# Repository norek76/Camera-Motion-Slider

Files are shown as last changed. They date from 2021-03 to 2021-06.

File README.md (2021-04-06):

# Camera Motion Slider with Pan Tilt Module

Hi,
since long time I was looking for a stable slider, that can handle the load of a system camera like the A7 together with heavy lenses. Second requirement was to keep the price low.

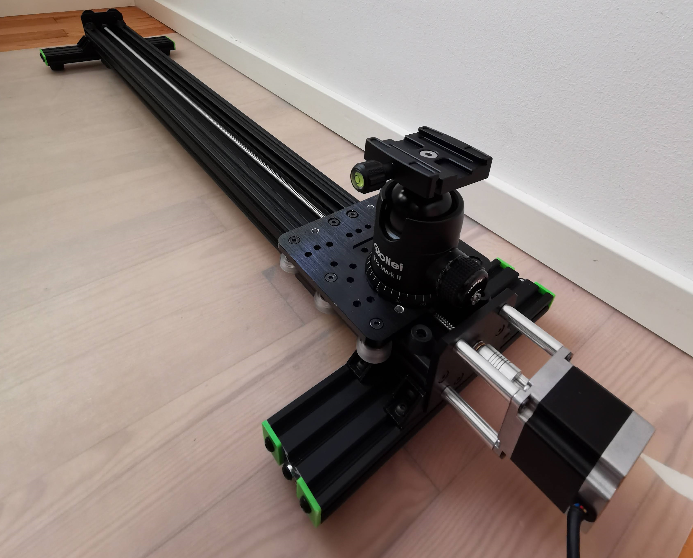
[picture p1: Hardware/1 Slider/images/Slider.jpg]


[Hardware - Slider](https://github.com/JoJ123/Camera-Motion-Slider/blob/master/Hardware/1%20Slider/README.md)

[Hardware - Pan Module](https://github.com/JoJ123/Camera-Motion-Slider/blob/master/Hardware/2%20Pan%20Module/README.md)

[Hardware - Tilt Module](https://github.com/JoJ123/Camera-Motion-Slider/blob/master/Hardware/3%20Tilt%20Module/README.md)

[Hardware - Controller](https://github.com/JoJ123/Camera-Motion-Slider/blob/master/Hardware/Controller/README.md)

[Software - ESP32](https://github.com/JoJ123/Camera-Motion-Slider/blob/master/Software/README.md)

[Software - Android](https://github.com/JoJ123/Camera-Motion-Slider/blob/master/Software/AndroidApp/README.md)

## Hardware Components
So here we are after 4 months of drawing, sketching and development here is the slider with pan and tilt module. It's a modular system with the following components:

 - Slider
 - Pan Module
 - Tilt Module

You can connect the three modules in the following configurations:
 - Slider
 - Slider with Pan Module (f.e. Timelapse)
 - Slider with Pan + Tilt Module (f.e. Timelapse)
 - Pan + Tilt Module (f.e. 360° Pano)

## Controller & Software
Last but not least there must be a controller. I started first to develope my "own" motion control library, after few weeks I stopped. And search for existing libs out there and there is a really powerfull open source library called "DFMoCo". It's the protocoll that is used by the software Dragonframe.

So I've started to check the source code of this library, that was build for Arduino Board with just USB Serial support. I've migrated the library to support ESP32 boards together with Bluetooth 4.0 that can be used also with a Serial Bluetooth Application from Android/iOS. The ESP32 can controll up to 4 stepper motors with this library. The library is command based.
In addition to the functionalities of DFMoCo I've added the possibility to focus / shutter an image of the camera with a headphone jack. Most camera manufactors support this way.

To be able to controll the slider also outside of my home I found a really good powerbank from the company XTPower. Product Name: [XT-20000QC3](https://www.xtpower.de/XT-20000Q3-Powerbank-mobiler-externer-USB-Akku-mit-20100mAh)
With this PowerBank I'm was able to reach the following operation times:
- 1 motor:  7.5h
- 2 motors: 5h
- 3 motors: 2.5h

You can easily connect two of them to increase the time. There is also a newer version of the PowerBank [XT-20000QC3-AO-PA](https://www.xtpower.de/XT-20000Q3-AO-PA-Powerbank-ohne-Abschaltung) without the automatic turnoff, when the power consumption is below 4-5W. If you build your controller wihtout a fan f.e. it would be better to choose this model, to keep the microcontroller running.
 
Possible commands:
- Move Motor 1-4 to position x
- Set Speed / Acc Ramp
- Focus / Shutter Camera Controll
- Timelapse with start / end position, timer, image shutter
- Panorama (full squere possible)

The controller for sure still supports the Dragonframe software.

To control the Slider / Camera Module easily also outside of the home, I've written a small Android application.

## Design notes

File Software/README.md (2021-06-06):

# DFMocoESP32
Forked from Dragonframe DFMoCo v.1.3.1

## Open Points
- Panorama Delay 100 after image shot

## Migration for ESP32-WROOM-32 Board (ESP32-DevKitC V4)
- channel 1
  - PIN  16   step
  - PIN  17   direction
- channel 2
  - PIN  18   step
  - PIN  19   direction
- channel 3
  - PIN  22   step
  - PIN  23   direction
- channel 4
  - PIN  32   step
  - PIN  33   direction
  
## Serial over USB / Bluetooth
If you want to use Bluetooth Classic, you have to set Pin35 to HIGH(Vcc), after that you can connect any Serial Bluetooth Application to the Board. The name of the bluetooth device is _DFMoCo_BT_.

## Camera Mode
You can check the different status codes at the code (~line 320)
```
cm --> Current camera mode status
- Timelapse: cm 1 [status] [executionStatus] [currentImageCounter] [imagesCount] 
- Panorama: cm 2 [status] [executionStatus] [currentRowCounter] [imagesRow] [currentColumnCounter] [imagesColumn] [exposureTimeMillis] [restMoveTime]

cr --> Reset camera mode
```

## Timelapse
Shoot a standalone timelapse, after the setup you can disconnect the phone. // TODO UPDATE!
```
tl [imageCount] [intervalSeconds] [exposureTimeMilliSeconds] [motionRestTimeMilliSeconds] [[motorNumber] [startPosition] [endPosition]]*
```
Example:
100 images, interval 5 seconds, exposure 150ms, restTimeAfterMovement 50ms, Motor1: 0 --> 1000, Motor2: 0 --> 500
```
tl 100 5 150 50 1 0 1000 2 0 500
```
## Panorama
Shoot a standalone timelapse, after the setup you can disconnect the phone.
```
pa [motorNumber] [imagesRow] [stepsRow] [motorNumber] [imagesColumn] [stepsColumn] [exposureTimeMilliSeconds] [motionRestTimeMilliSeconds]
```
Example:
30° Row, 30° Column --> 360°/30° = 12 Images, 200Row, 400 Column, Motor1: 0, Motor2: 0
```
pa 1 12 200 2 12 400 1000 5000
```

## Version History
- Version 1.6.0 Timelapse Multi Position with Ramping
- Version 1.5.2 Add standalone panorama mode
- Version 1.5.1 Add standalone timelapse mode
- Version 1.5.0 Add Camera Focus / Shutter
- Version 1.4.1 Support acceleration
- Version 1.4.0 ESP32-WROOM-32 support with Serial Bluetooth Classic
- Version 1.3.1 Report if go-motion speed cannot be reached.
- Version 1.3.0 Arduino 101 support. Remove non-Arduino support (chipKit, Maple).
- Version 1.2.7 Direction setup time.
- Version 1.2.6 Add PINOUT_VERSION option to use older pinout.
- Version 1.2.5 Fix jogging with low pulse rate.
- Version 1.2.4 Fix pin assignments
- Version 1.2.3 New Position command
- Version 1.2.2 Jog and Inch commands
- Version 1.2.1 Moved step/direction pins for motions 5-8. Detects board type automatically.
- Version 1.2.0 Basic go-motion capabilities
- Version 1.1.2 Smooth transitions when changing direction
- Version 1.1.1 Save/restore motor position
- Version 1.1.0 Major rework 
- Version 1.0.2 Moved pulses into interrupt handler
- Version 1.0.1 Added delay for pulse widths  
- Version 1.0.0 Initial public release.

"board": "espressif:esp32:esp32",
"configuration": "PSRAM=disabled,PartitionScheme=default,CPUFreq=240,FlashMode=qio,FlashFreq=80,FlashSize=4M,UploadSpeed=921600,DebugLevel=none",

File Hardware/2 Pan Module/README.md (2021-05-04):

# Pan Module
For the pan module I was trying multiple approaches (F.e. "Pulleys with a strip or Nema23 alone"). The problem was, that the components became to huge.
In the end I found a really simple way. It's a direct connection between the Motor (Nema17 with a planetary gearbox) and a Mengs DM-60 Base. I've designed my own motor mount plate.

I'm using here an additional Mengs FNR-140 to center the nodal point of the camera lens in the rotation axis.

I've chosen here an Nema17 with 1.8° per Full Step together with a 27:1 Gearbox

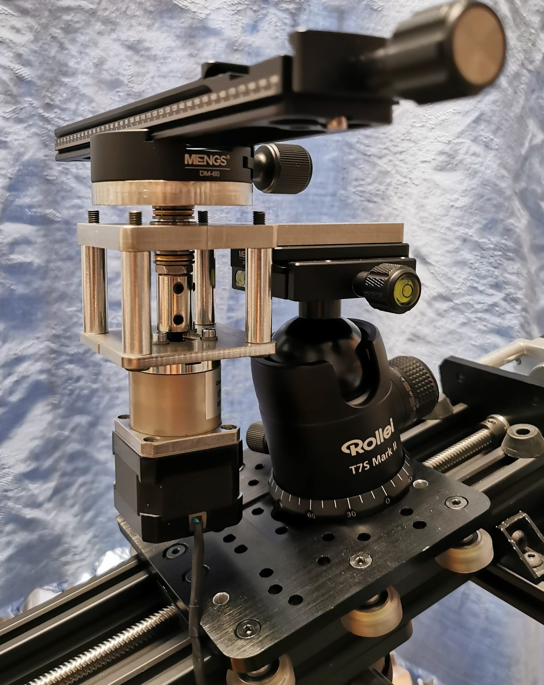
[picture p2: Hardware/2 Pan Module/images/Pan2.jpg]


```
I can't promise that this list is complete
```

Part List Pan:
* Motor Pan Plate (check the [step file](https://github.com/JoJ123/Camera-Motion-Slider/blob/master/Hardware/2%20Pan%20Module/parts/MotorPanModule.step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) & [drawing](https://github.com/JoJ123/Camera-Motion-Slider/blob/master/Hardware/2%20Pan%20Module/parts/MotorPanModule.pdf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))
* Motor Adapter Plate (check the [step file](https://github.com/JoJ123/Camera-Motion-Slider/blob/master/Hardware/2%20Pan%20Module/parts/MotorAdapterPlate.step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) & [drawing](https://github.com/JoJ123/Camera-Motion-Slider/blob/master/Hardware/2%20Pan%20Module/parts/MotorAdapterPlate.pdf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))
* Camera Base Plate (check the [step file](https://github.com/JoJ123/Camera-Motion-Slider/blob/master/Hardware/2%20Pan%20Module/parts/CameraBasePlate.step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) & [drawing](https://github.com/JoJ123/Camera-Motion-Slider/blob/master/Hardware/2%20Pan%20Module/parts/CameraBasePlate.pdf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))
* Nema17 1.8degree (max 2.0A) 27:1 Gearbox (check the max length!)
* Motor Coupling Fixed Version! 
* Spacers (40mm) (4x)
* Center Screw M8 (1x)
* Mengs DM-60 (1x)
* Mengs PU-70 (1x)
* iShoot QS-120 (1x)
* 16x8x5 Radial Flanged Bearing (688ZZ Flanged) (2x)
* 16x8x5 Axial Bearing (Silber/Gold) (2x)
+ M8 Nut (DIN 439) Thin Version (1x)
* Washers & Screws
  * 12x8 Washer
  * Screws (M5)

## Assembly
Cut the M5 thread in the Camera Base Plate & Motor Pan Plate
Connect all part like on the images below.

The stack will look like that:

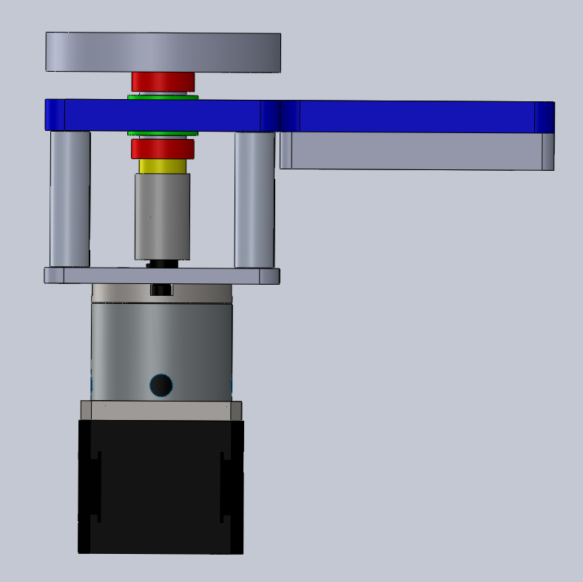
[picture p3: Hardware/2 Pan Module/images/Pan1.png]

- Red is the 16x8x5 Axial Bearing
- Green is the 688ZZ Flanged
- Gray is a 12x8 Washer
- Ignore the flexible motor coupling, it must be a fixed one here!
- I've used a flanged screw from the top to the bottom. Starting from the Mengs DN-60 that is fixed on top of the camera plate.

## Pan Module Image
You can also use the pan module directly on a tripod, as the base for an panorma image.

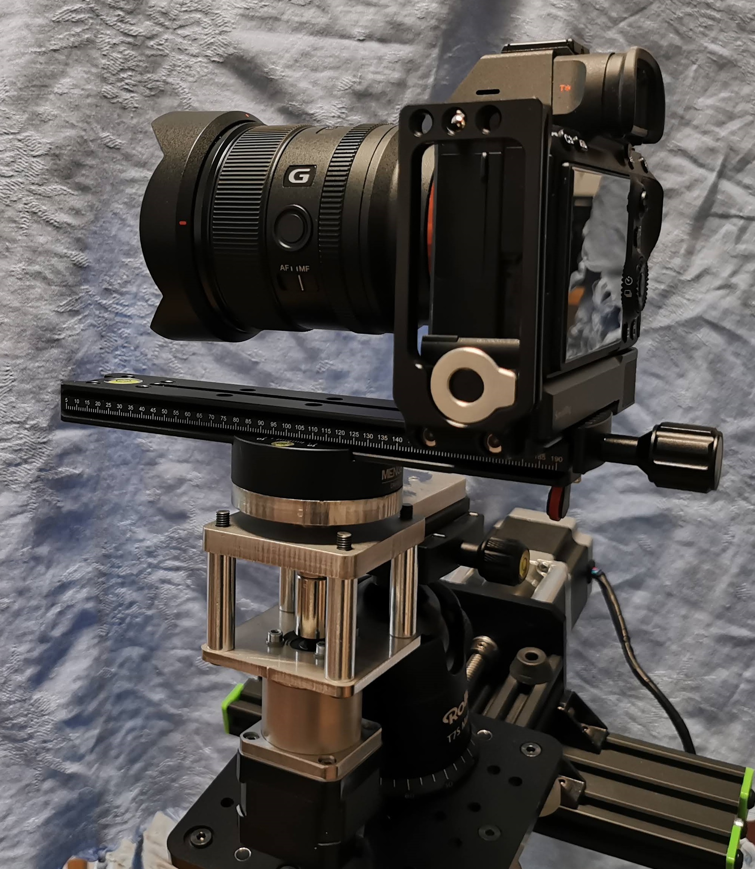
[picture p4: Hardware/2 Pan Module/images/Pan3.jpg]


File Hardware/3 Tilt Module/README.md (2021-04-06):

# Tilt Module
The tilt module is similar to the pan module, just some plates are different.

I'm also using here the same Mengs FNR-140 to center the camera in the rotation axis.

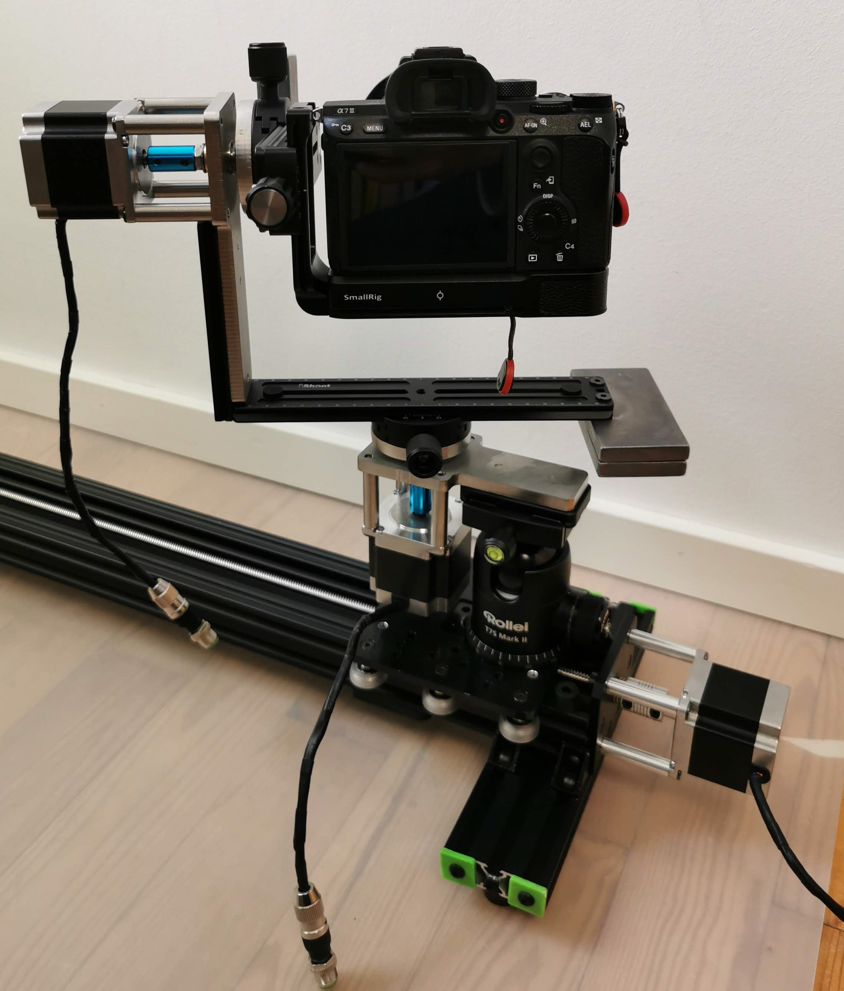
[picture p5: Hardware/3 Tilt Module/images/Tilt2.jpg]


```
I can't promise that this list is complete
```

Part List Tilt:
* Motor Tilt Plate (check the [step file](https://github.com/JoJ123/Camera-Motion-Slider/blob/master/Hardware/3%20Tilt%20Module/parts/MotorTiltModule.step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) & [drawing](https://github.com/JoJ123/Camera-Motion-Slider/blob/master/Hardware/3%20Tilt%20Moduleparts/MotorTiltModule.pdf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))
* Camera Base Plate (check the [step file](https://github.com/JoJ123/Camera-Motion-Slider/blob/master/Hardware/3%20Tilt%20Module/parts/CameraBasePlate.step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) & [drawing](https://github.com/JoJ123/Camera-Motion-Slider/blob/master/Hardware/3%20Tilt%20Module/parts/CameraBasePlate.pdf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))
* Nema23 0.9degree (max 2.0A)
* Motor Coupling Fixed Version! 
* Spacers (40mm) (4x)
* Center Screw M8 (1x)
* Mengs DM-60 (1x)
* Mengs PU-70 (1x)
* iShoot QS-120 (1x)
* iShoot QS-220 (1x)
* 16x8x5 Radial Flanged Bearing (688ZZ Flanged) (2x)
* 16x8x5 Axial Bearing (Silber/Gold) (2x)
+ M8 Nut (DIN 439) Thin Version (1x)
* Washers & Screws
  * 12x8 Washer
  * Screws (M5)

## Assembly
Cut the M5 thread in the Camera Base Plate & Motor Tilt Plate
Connect all part like on the images below.

The stack will look like that:

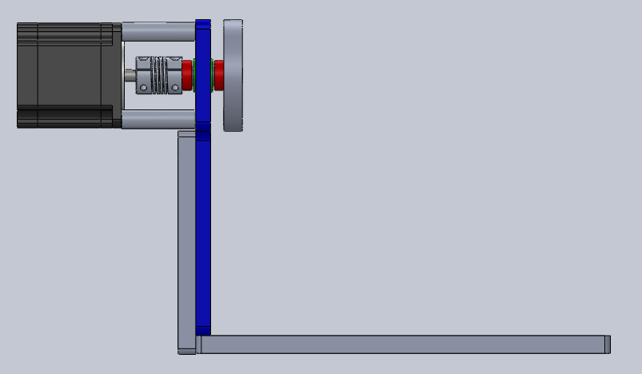
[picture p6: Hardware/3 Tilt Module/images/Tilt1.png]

- Red is the 16x8x5 Axial Bearing
- Green is the 688ZZ Flanged
- Gray is a 12x8 Washer
- Ignore the flexible motor coupling, it must be a fixed one here!
- I've used a flanged screw from the right to the left. Starting in the Mengs DN-60 that is fixed on the camera plate

## Tilt Module Images
You can use the pan & tilt module together as a 360° panorama head.
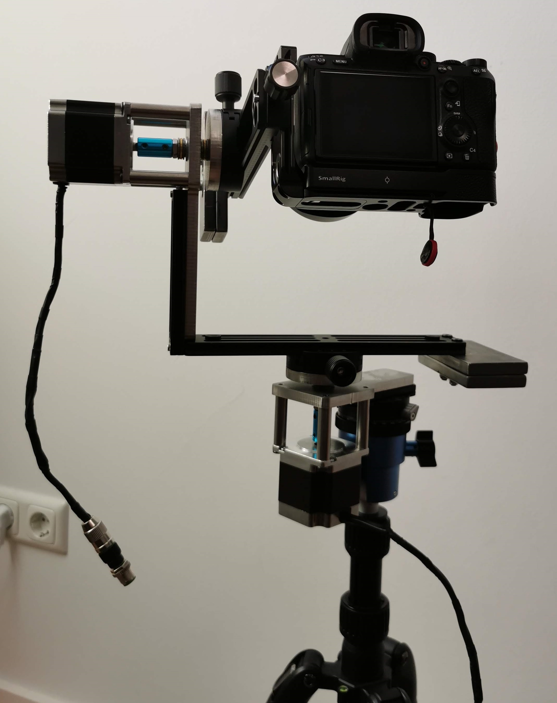
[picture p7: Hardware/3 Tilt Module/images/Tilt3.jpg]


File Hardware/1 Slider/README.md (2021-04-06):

# Base with Pan

The base for the slider was build from parts available under the "OpenBuild" Brands. I was ordering my stuff from a seller in Portugal, that is shipping to Germany. Some parts like the Motor Mount Plate is a bit different in their store. The following list is build from the parts available at this seller.
Some other parts like motors, ... were ordered by ebay.

I've chosen here an Nema23 with 1.8°/Full Step
The Lead Screw will move the slider 8mm with one rotation.



```
I can't promise that this list is complete
```

Part List Base:
* 1m C*Beam
* Motor Mount Plate (2x) --> The new one with 4 motor screws
* 16x8x5 Radial Bearing (688ZZ) (2x)
* 16x8x5 Axial Bearing (Silber/Gold) (2x)
* ACME 8mm Lead Screw (1040mm)
* Nema23 1.8degree (max 2.0A)
* Motor Coupling
* Nut Block for 8mm Metric Acme Lead Screw (2x)
* Spacers (3mm) (4x)
* Spacers (40mm) (4x)
* C-Beam Gantry Plate - XLarge
* Solid V Wheel Kit (6x)
* Spacers 6mm (3x)
* Excentric Spacers (3x)
* Rollei T7S Mark II (Or any other heavy ballhead)
* Arca Swiss Plates (2x)
* Big Tripod Plates (2x)
* Washers & Screws
  * 12x8
  * Screws

## Motor Connection
I'm using M12 Sensor Connector. I got a few of them for a good price, but you can use mostly any connector that is available. The good thing about this M12 Sensor Plugs is, that there is also a lot of different extension cables available.

## Slider
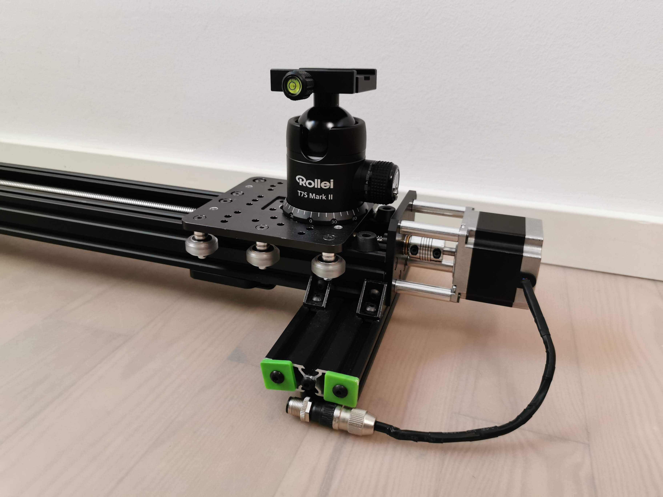
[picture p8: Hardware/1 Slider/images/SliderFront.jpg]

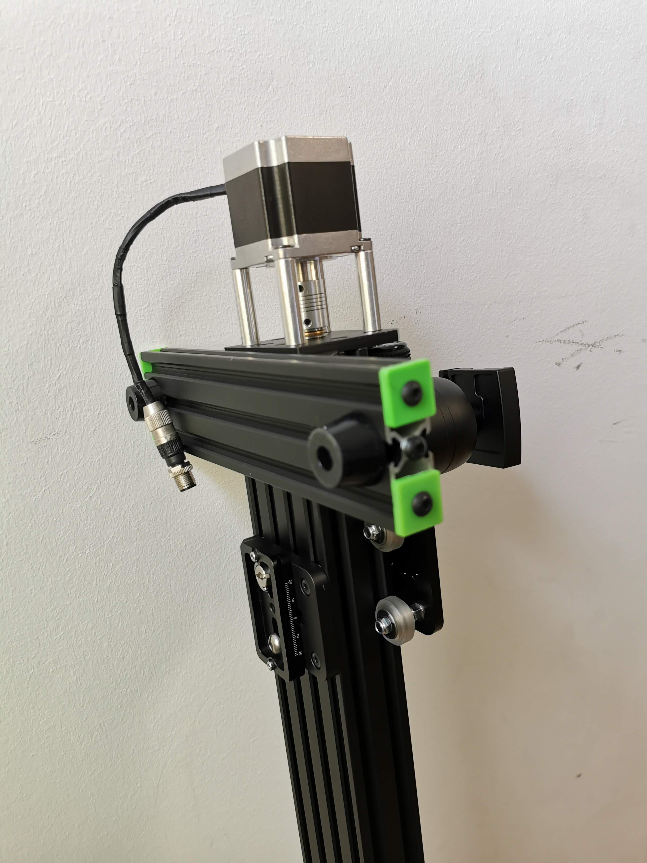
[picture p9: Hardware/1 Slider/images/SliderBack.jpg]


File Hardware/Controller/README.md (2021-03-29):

# Controller
The controller is based on a ESP32 with an CNC Shield V3 board. It looks really like a prototype :D It is a prototype.

If you have any interest in building a similar controller I would be happy to work together on a version with a PCB design. 

Contact me! :)

To be able to use the controller also outside of my home I found a really good powerbank from the company XTPower. Product Name: [XT-20000QC3](https://www.xtpower.de/XT-20000Q3-Powerbank-mobiler-externer-USB-Akku-mit-20100mAh)
With this PowerBank I'm was able to reach the following operation times:
- 1 motor:  7.5h
- 2 motors: 5h
- 3 motors: 2.5h

To connect the Powerbank to the controller you can use an XT60 to DC 5.5 2.1mm adapter, you will find it on one of the big electronic online stores or build it yourself.

You can easily connect two of them to increase the time. There is also a newer version of the PowerBank [XT-20000QC3-AO-PA](https://www.xtpower.de/XT-20000Q3-AO-PA-Powerbank-ohne-Abschaltung) without the automatic turnoff, when the power consumption is below 4-5W. If you build your controller wihtout a fan f.e. it would be better to choose this model, to keep the microcontroller running.

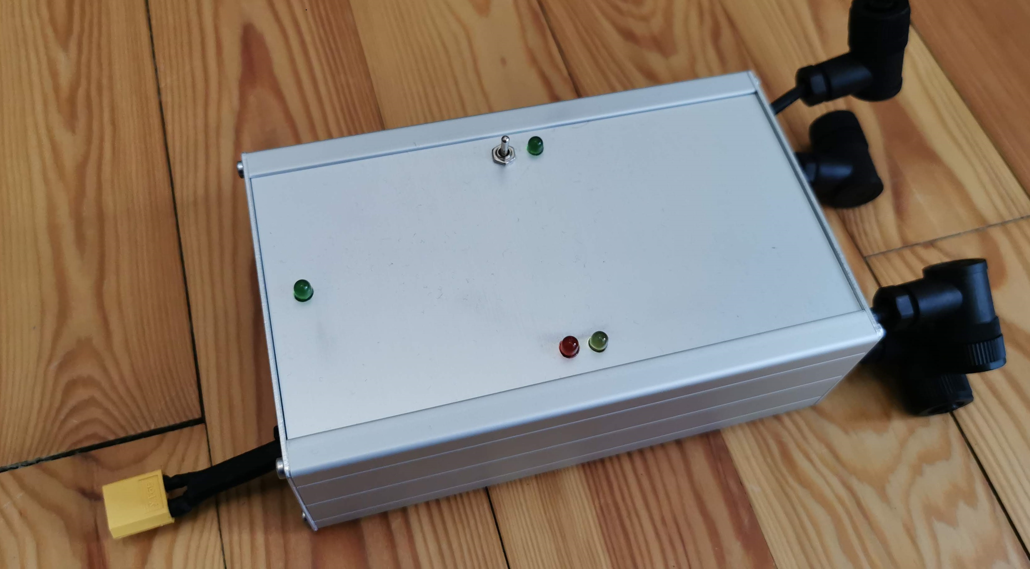
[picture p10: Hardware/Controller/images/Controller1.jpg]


Components:
- Hoisting (Proma 131030) - 168 x 103 x 56 Aluminium
- Lochrasterplatine 160mm x 100mm 
- ESP32 Dev Kit C V4
- CNC Shield v3 Board
- StepDown Board to 5V (PowerSupply ESP and fan)
- XT60 Connector
- 5V Mini Fan
- 3.5mm Audio Jack 
- PNP Transistor (for the camera focus/shutter)
- M12 Connector
- few Resistors, LEDs & Switches

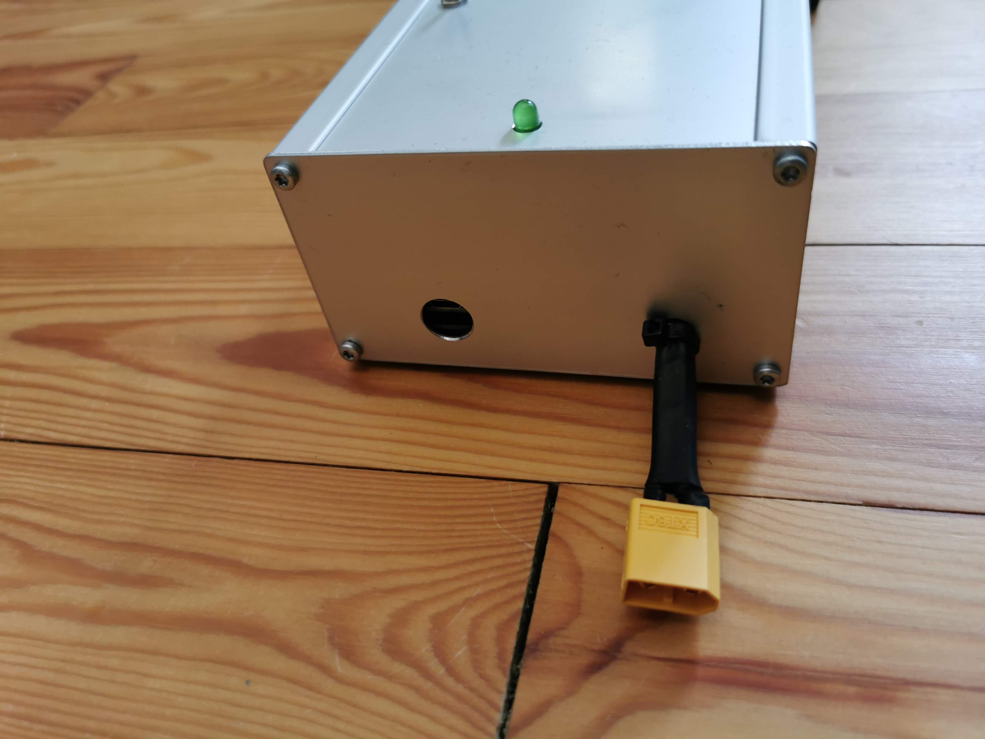
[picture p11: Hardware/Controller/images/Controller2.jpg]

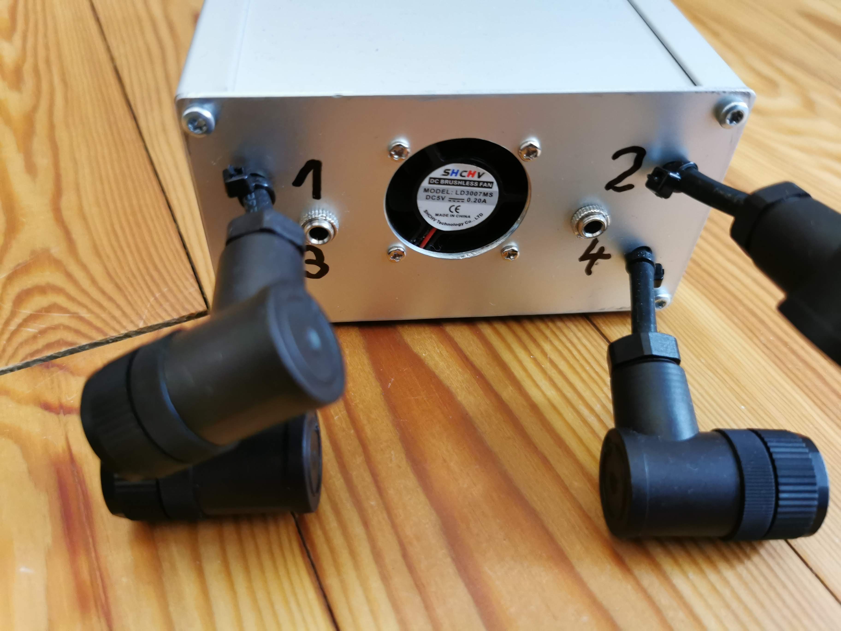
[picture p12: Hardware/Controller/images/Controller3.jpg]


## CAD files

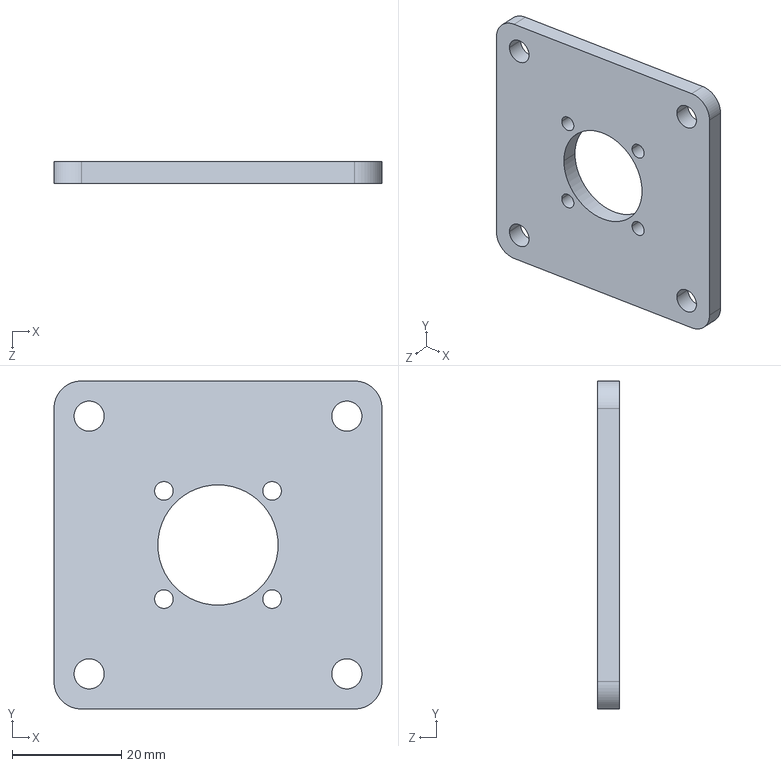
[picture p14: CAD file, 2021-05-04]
Hardware/2 Pan Module/parts/MotorAdapterPlate.step
60.0 x 60.0 x 4.00 mm

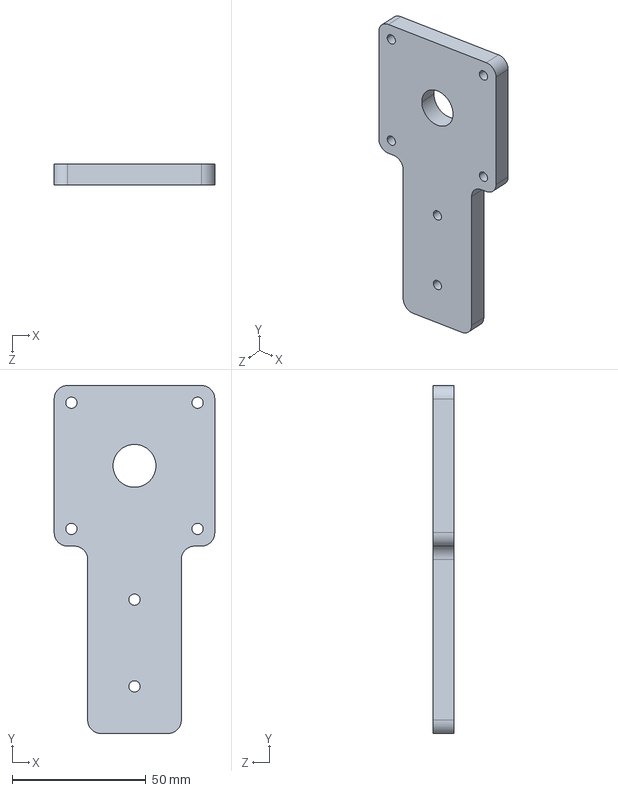
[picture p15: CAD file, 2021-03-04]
Hardware/2 Pan Module/parts/MotorPanModule.step
60.0 x 130.0 x 8.00 mm

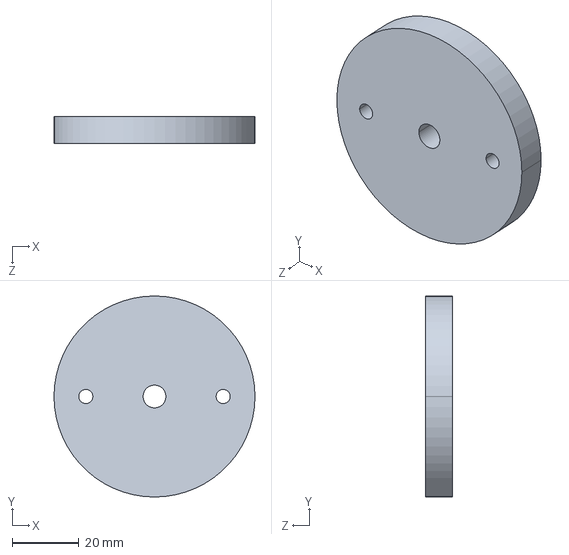
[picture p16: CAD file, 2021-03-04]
Hardware/3 Tilt Module/parts/CameraBasePlate.step
60.0 x 60.0 x 8.00 mm

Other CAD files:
Hardware/3 Tilt Module/parts/MotorTiltModule.step

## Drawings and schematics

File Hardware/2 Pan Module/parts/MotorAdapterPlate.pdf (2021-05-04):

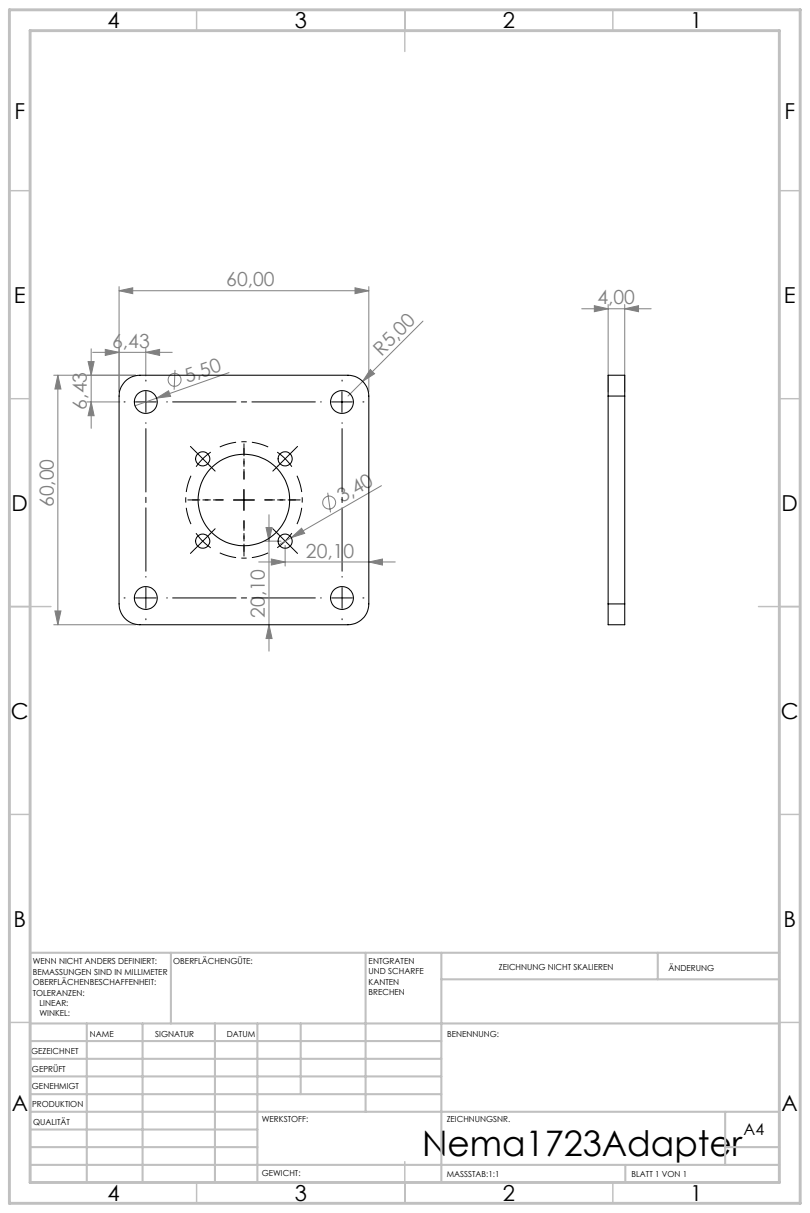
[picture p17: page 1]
MASSSTAB:1:1; BLATT 1 VON 1; ZEICHNUNG NICHT SKALIEREN; ÄNDERUNG; UND SCHARFE; WENN NICHT ANDERS DEFINIERT:; OBERFLÄCHENGÜTE:

BEMASSUNGEN SIND IN MILLIMETER
OBERFLÄCHENBESCHAFFENHEIT:
TOLERANZEN:
LINEAR:
WINKEL:

NAME | SIGNATUR | DATUM | | | | BENENNUNG:
QUALITÄT | | | | WERKSTOFF: Nema1723Adapter GEWICHT: | ZEICHNUNGSNR. | A4

GEZEICHNET
GEPRÜFT
GENEHMIGT
PRODUKTION

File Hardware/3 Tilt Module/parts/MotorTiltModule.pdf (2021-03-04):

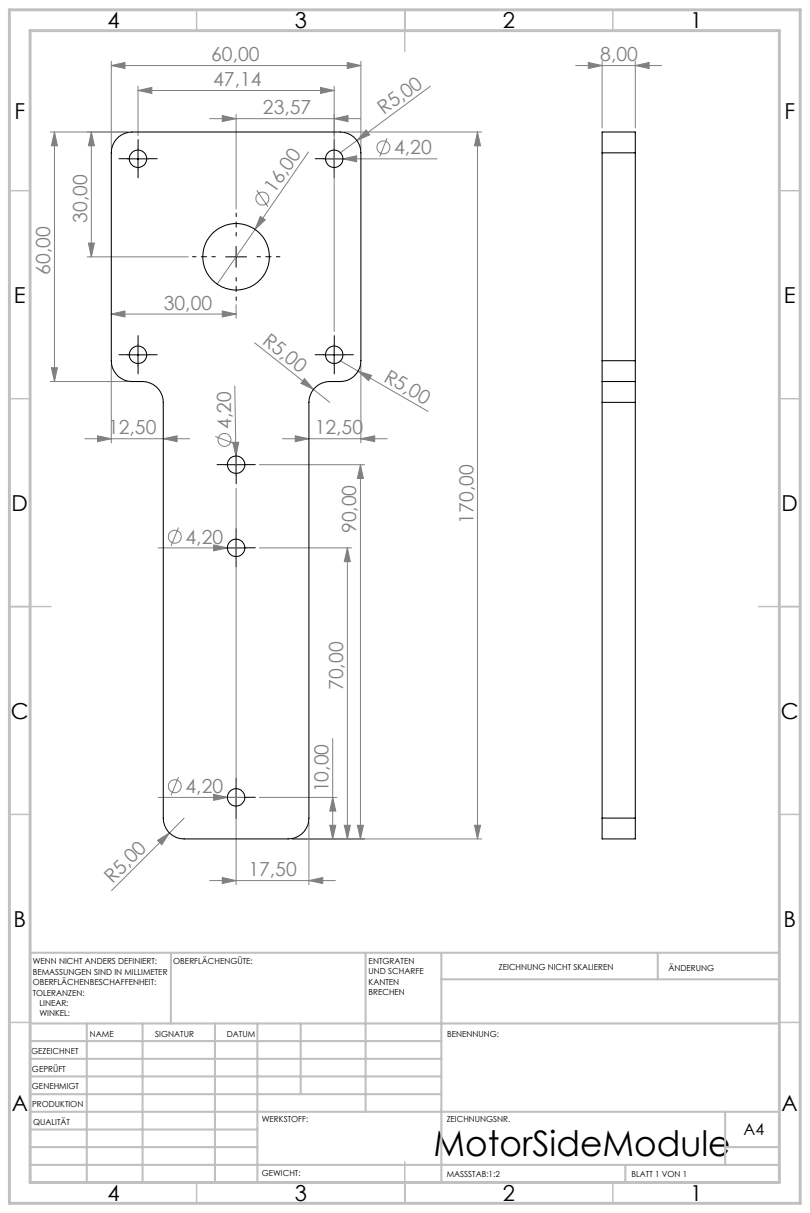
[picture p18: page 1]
MASSSTAB:1:2; BLATT 1 VON 1; ZEICHNUNG NICHT SKALIEREN; ÄNDERUNG; UND SCHARFE; WENN NICHT ANDERS DEFINIERT:; OBERFLÄCHENGÜTE:

BEMASSUNGEN SIND IN MILLIMETER
OBERFLÄCHENBESCHAFFENHEIT:
TOLERANZEN:
LINEAR:
WINKEL:

NAME | SIGNATUR | DATUM | | | | BENENNUNG:
QUALITÄT | | | | WERKSTOFF: MotorSideModule GEWICHT: | ZEICHNUNGSNR. | A4

GEZEICHNET
GEPRÜFT
GENEHMIGT
PRODUKTION

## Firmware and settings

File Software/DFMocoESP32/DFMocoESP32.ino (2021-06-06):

#include <Arduino.h>
#include <math.h>
#include <BluetoothSerial.h>

#define DFMOCO_VERSION 1
#define DFMOCO_VERSION_STRING "1.6.0"

#define USER_CMD_ARGS 40
struct UserCmd
{
  byte command;
  byte argCount;
  int32_t args[USER_CMD_ARGS];
};

boolean availableSerial();
int readSerial();
void bluetoothCallback(esp_spp_cb_event_t event, esp_spp_cb_param_t *param);
void IRAM_ATTR updateStepDirection(void);
void hardStop();
void updateMotorVelocities();
void setMaxAccelerationPerSecond(int motorIndex, uint16_t accelerationPerSecond);
void setPulsesPerSecond(int motorIndex, uint16_t pulsesPerSecond, boolean setRamp = false);
void setupMotorMove(int motorIndex, int32_t destination);
void stopMotor(int motorIndex, boolean fastStop = false, boolean hardStop = false);
boolean isValidMotor(int motorIndex);
void processGoPosition(int motorIndex, int32_t pos);
byte processUserMessage(char data);
void processSerialCommand();
void sendMessage(byte msg, byte motorIndex);
void sendMessageQueue(byte msg, byte motorIndex);
boolean jogMotor(int motorIndex, int32_t target, int32_t *destination);
void inchMotor(int motorIndex, int32_t target);
void calculatePointToPoint(int motorIndex, int32_t destination);
int32_t setupBlur(int motorIndex, int exposure, int blur, int32_t p0, int32_t p1, int32_t p2);
void IRAM_ATTR delayMilliseconds(uint32_t us);
void takeCameraImage(int delayFocus, int delayShutter);
void setCameraFocus(boolean value);
void setCameraShutter(boolean value);
void resetCameraMode();
void resetCameraModeSettings();
void processCameraMode();
void IRAM_ATTR executeTimelaseMotion(void);
void IRAM_ATTR executeTimelapseImage();
void setupTimelapse(UserCmd userCmd);
void processTimelapse();
void setupPanorama(UserCmd userCmd);
void processPanorama();

/*
  DFMoco version 1.5.2
  
  Multi-axis motion control.
  For use with the Arc motion control system in Dragonframe 4.
  Generates step and direction signals, which can be sent to stepper motor drivers.

  Version History
  Version 1.5.2 Add standalone panorama mode
  Version 1.5.1 Add standalone timelapse mode
  Version 1.5.0 Add standalone timelapse mode
  Version 1.4.1 Support acceleration
  Version 1.4.0 ESP32-WROOM-32 support with Serial Bluetooth Classic
  Version 1.3.1 Report if go-motion speed cannot be reached.
  Version 1.3.0 Arduino 101 support. Remove non-Arduino support (chipKit, Maple).
  Version 1.2.7 Direction setup time.
  Version 1.2.6 Add PINOUT_VERSION option to use older pinout.
  Version 1.2.5 Fix jogging with low pulse rate.
  Version 1.2.4 Fix pin assignments
  Version 1.2.3 New Position command
  Version 1.2.2 Jog and Inch commands
  Version 1.2.1 Moved step/direction pins for motions 5-8.
                Detects board type automatically.
  Version 1.2.0 Basic go-motion capabilities
  Version 1.1.2 Smooth transitions when changing direction
  Version 1.1.1 Save/restore motor position
  Version 1.1.0 Major rework 
  Version 1.0.2 Moved pulses into interrupt handler
  Version 1.0.1 Added delay for pulse widths  
  Version 1.0.0 Initial public release.
*/

#define SERIAL_DEVICE Serial
#define SERIAL_DEVICE_BT SerialBT
#define BLUETOOTH_LED_PIN 26

#define FOCUS_PIN 14
#define SHUTTER_PIN 27
#define ENABLE_PIN 25

#define PIN_ON(port, pin) \
  {                       \
    digitalWrite(pin, 1); \
  }
#define PIN_OFF(port, pin) \
  {                        \
    digitalWrite(pin, 0);  \
  }

#define MOTOR_COUNT 4
#define TIME_CHUNK 50
#define SEND_POSITION_COUNT 20000

// update velocities 20 x second
#define VELOCITY_UPDATE_RATE (50000 / TIME_CHUNK)
#define VELOCITY_INC(maxrate) (max(1.0f, maxrate / 70.0f))
#define VELOCITY_CONVERSION_FACTOR 0.30517578125f /* 20 / 65.536f */

#define MAX_VELOCITY 12000
#define DEFAUL_VELOCITY 1500
#define MIN_VELOCITY 100
#define MAX_ACCELERATION 2 * MAX_VELOCITY
#define MIN_ACCELERATION 2 * MIN_VELOCITY

#define MOTOR0_STEP_PORT 0
#define MOTOR0_STEP_PIN 16

#define MOTOR1_STEP_PORT 0
#define MOTOR1_STEP_PIN 18

#define MOTOR2_STEP_PORT 0
#define MOTOR2_STEP_PIN 22

#define MOTOR3_STEP_PORT 0
#define MOTOR3_STEP_PIN 32

#define TX_UCSRA UCSR0A
#define TX_UDRE UDRE0
#define TX_UDR UDR0
char txBuf[32];
char *txBufPtr;

#define TX_MSG_BUF_SIZE 16

#define MSG_STATE_START 0
#define MSG_STATE_CMD 1
#define MSG_STATE_DATA 2
#define MSG_STATE_ERR 3

#define MSG_STATE_DONE 100

/*
 * Command codes from user
 */
#define CMD_NONE 0
#define CMD_HI 10
#define CMD_MS 30
#define CMD_NP 31
#define CMD_MM 40 // move motor
#define CMD_PR 41 // pulse rate
#define CMD_SM 42 // stop motor
#define CMD_MP 43 // motor position
#define CMD_ZM 44 // zero motor
#define CMD_SA 50 // stop all (hard)
#define CMD_BF 60 // blur frame
#define CMD_GO 61 // go!

#define CMD_JM 70 // jog motor
#define CMD_IM 71 // inch motor

#define CMD_VE 80 // velocity
#define CMD_AC 81 // acceleration

#define CMD_CF 90 // camera focus
#define CMD_CS 91 // camera shutter
#define CMD_CI 92 // camera take image

#define CMD_CM 100 // camera mode
#define CMD_CR 101 // reset camera mode
#define CMD_TL 102 // timelapse
#define CMD_PA 103 // panorama

// pa 1 10 160 2 3 200 5000 1000

#define MSG_HI 01
#define MSG_MM 02
#define MSG_MP 03
#define MSG_MS 04
#define MSG_PR 05
#define MSG_SM 06
#define MSG_SA 07
#define MSG_BF 10
#define MSG_GO 11
#define MSG_JM 12
#define MSG_IM 13
#define MSG_AC 14
#define MSG_VE 15
#define MSG_CM 16
#define MSG_CR 17

#define CAM_MODE_NONE 0
#define CAM_MODE_TIMELAPSE 1
#define CAM_MODE_PANORAMA 2
#define CAM_MODE_RESETTING 10

// Timelapse Status
#define TIMELAPSE_SETUP 0
#define TIMELAPSE_RUNNING 1
#define TIMELAPSE_DONE 2
// Timelapse EXECUTION
#define TIMELAPSE_INIT_MOVEMENT 0
#define TIMELAPSE_START_EXECUTION 1
#define TIMELAPSE_REST 2
#define TIMELAPSE_IMAGE 3
#define TIMELAPSE_MOVE 4
// Timelapse Errors
#define TIMELAPSE_ERROR_INTERVAL_LT_1 10
#define TIMELAPSE_ERROR_EXPOSURE_LT_1 11
#define TIMELAPSE_ERROR_REST_LT_0 12
#define TIMELAPSE_ERROR_POSITION_COUNT_BETWEEN_2_4 13
#define TIMELAPSE_ERROR_IMAGES_LE_1 14
#define TIMELAPSE_ERROR_IMAGES_NOT_IN_ROW 15
#define TIMELAPSE_ERROR_RAMP_BETWEEN_0_40 16
#define TIMELAPSE_ERROR_ACC_RAMP 17
#define TIMELAPSE_ERROR_MOVE_SHOOT_TIME 18
#define TIMELAPSE_ERROR_POSITION 19
// Panorama Status
#define PANORAMA_SETUP 0
#define PANORAMA_RUNNING 1
#define PANORAMA_DONE 2
// Panorama Execution Status
#define PANORAMA_REST 0
#define PANORAMA_REST_RUNNING 1
#define PANORAMA_IMAGE 2
#define PANORAMA_READY_FOR_MOVE 3
#define PANORAMA_MOVE 4
#define PANORAMA_MOVE_END 5
// Panorama Errors
#define PANORAMA_ERROR_MTR_OUT 10
#define PANORAMA_ERROR_IMG_LE_1 11
#define PANORAMA_ERROR_STP_EQ_0 12
#define PANORAMA_ERROR_EXP_LT_50 13
#define PANORAMA_ERROR_RST_LT_1 14

#define MAX_POSITION_COUNT 4
#define MAX_ITERATION_COUNT MAX_POSITION_COUNT - 1

struct TimelapseMotor
{
  boolean enable;
  int32_t time[MAX_ITERATION_COUNT][4];
  double acc[MAX_ITERATION_COUNT];
  double dec[MAX_ITERATION_COUNT];
  double v0[MAX_ITERATION_COUNT];
  double v1[MAX_ITERATION_COUNT];
  uint32_t velocity;
  uint32_t acceleration;
  int32_t positions[MAX_POSITION_COUNT];
  int32_t lastPosition;
};

struct Timelapse
{
  TimelapseMotor motors[MOTOR_COUNT];
  uint32_t intervalSeconds;
  uint32_t imagesCount[3];
  uint32_t exposureTimeMillis;
  uint32_t restMoveTime;
  uint32_t ramp;
  uint32_t positionCount;
  uint32_t currentIteration;
  uint32_t currentIterationImageCounter;
  uint32_t totalImageCounter;
  uint32_t totalImages;
  byte status;
  byte executionStatus;
};

Timelapse timelapseData;

struct Panorma
{
  uint32_t motorRow;
  uint32_t imagesRow;
  int32_t stepsRow;
  uint32_t motorColumn;
  uint32_t imagesColumn;
  int32_t stepsColumn;
  uint32_t exposureTimeMillis;
  uint32_t restMoveTime;
  uint32_t restStartMillis;
  uint32_t currentRowCounter;
  uint32_t currentColumnCounter;
  byte status;
  byte executionStatus;
};

Panorma panoramaData;
/*
 * Message state machine variables.
 */
byte lastUserData;
int msgState;
int msgNumberSign;
UserCmd userCmd;

struct txMsg
{
  byte msg;
  byte motor;
};

struct TxMsgBuffer
{
  txMsg buffer[TX_MSG_BUF_SIZE];
  byte head;
  byte tail;
};

TxMsgBuffer txMsgBuffer;
BluetoothSerial SerialBT;

/*
 Motor data.
 */
uint16_t motorAccumulator0;
uint16_t motorAccumulator1;
uint16_t motorAccumulator2;
uint16_t motorAccumulator3;
uint16_t *motorAccumulator[MOTOR_COUNT] =
    {
        &motorAccumulator0,
        &motorAccumulator1,
        &motorAccumulator2,
        &motorAccumulator3,
};

uint16_t motorMoveSteps0;
uint16_t motorMoveSteps1;
uint16_t motorMoveSteps2;
uint16_t motorMoveSteps3;
uint16_t *motorMoveSteps[MOTOR_COUNT] =
    {
        &motorMoveSteps0,
        &motorMoveSteps1,
        &motorMoveSteps2,
        &motorMoveSteps3,
};

uint16_t motorMoveSpeed0;
uint16_t motorMoveSpeed1;
uint16_t motorMoveSpeed2;
uint16_t motorMoveSpeed3;
uint16_t *motorMoveSpeed[MOTOR_COUNT] =
    {
        &motorMoveSpeed0,
        &motorMoveSpeed1,
        &motorMoveSpeed2,
        &motorMoveSpeed3,
};

volatile boolean nextMoveLoaded;

unsigned int velocityUpdateCounter;
byte sendPositionCounter;

byte sendPosition = 0;
byte motorMoving = 0;
byte toggleStep = 0;

#define P2P_MOVE_COUNT 7
struct Motor
{
  byte stepPin;
  byte dirPin;

  // pre-computed move
  float moveTime[P2P_MOVE_COUNT];
  int32_t movePosition[P2P_MOVE_COUNT];
  float moveVelocity[P2P_MOVE_COUNT];
  float moveAcceleration[P2P_MOVE_COUNT];

  float gomoMoveTime[P2P_MOVE_COUNT];
  int32_t gomoMovePosition[P2P_MOVE_COUNT];
  float gomoMoveVelocity[P2P_MOVE_COUNT];
  float gomoMoveAcceleration[P2P_MOVE_COUNT];

  int currentMove;
  float currentMoveTime;

  volatile boolean positionReached;
  volatile boolean dir;

  int32_t position;
  int32_t destination;
  float maxVelocity;
  float maxAcceleration;

  uint16_t nextMotorMoveSteps;
  float nextMotorMoveSpeed;
};

boolean goMoReady;
int goMoDelayTime;

Motor motors[MOTOR_COUNT];

unsigned long lastBluetoothLedMillis = millis();
boolean serialBluetoothEnabled = false;

boolean lastBluetoothLedState = true;
hw_timer_t *timerMotion = NULL;
portMUX_TYPE timerMotionMux = portMUX_INITIALIZER_UNLOCKED;

hw_timer_t *timerCameraMode = NULL;
hw_timer_t *timerCameraModeMotion = NULL;

byte cameraMode = CAM_MODE_NONE;
QueueHandle_t messageQueue;
int messageCounter = 0;

class DualPrint : public Print
{
public:
  DualPrint() : serialBluetoothEnabled(false) {}
  virtual size_t write(uint8_t c)
  {
    if (serialBluetoothEnabled)
      SERIAL_DEVICE_BT.write(c);
    else
      SERIAL_DEVICE.write(c);
    return 1;
  }

  boolean serialBluetoothEnabled;
} dualSerial;

boolean availableSerial()
{
  if (serialBluetoothEnabled)
  {
    return SERIAL_DEVICE_BT.available();
  }
  return SERIAL_DEVICE.available();
}

int readSerial()
{
  if (serialBluetoothEnabled)
  {
    return SERIAL_DEVICE_BT.read();
  }
  return SERIAL_DEVICE.read();
}

void bluetoothCallback(esp_spp_cb_event_t event, esp_spp_cb_param_t *param)
{
  if (event == ESP_SPP_SRV_OPEN_EVT)
  {
    PIN_ON(0, BLUETOOTH_LED_PIN);
    dualSerial.serialBluetoothEnabled = true;
    serialBluetoothEnabled = true;
  }
  if (event == ESP_SPP_CLOSE_EVT)
  {
    dualSerial.serialBluetoothEnabled = false;
    serialBluetoothEnabled = false;
    lastBluetoothLedState = false;
    lastBluetoothLedMillis = millis();
    PIN_OFF(0, BLUETOOTH_LED_PIN);
  }
}

void IRAM_ATTR updateStepDirection(void)
{
  portENTER_CRITICAL_ISR(&timerMotionMux);
  toggleStep = !toggleStep;

  if (toggleStep)
  {
    // MOTOR 1
    if (motorMoveSteps0)
    {
      uint16_t a = motorAccumulator0;
      motorAccumulator0 += motorMoveSpeed0;
      if (motorAccumulator0 < a)
      {
        motorMoveSteps0--;

        PIN_ON(MOTOR0_STEP_PORT, MOTOR0_STEP_PIN);
      }
    }

    // MOTOR 2
    if (motorMoveSteps1)
    {
      uint16_t a = motorAccumulator1;
      motorAccumulator1 += motorMoveSpeed1;
      if (motorAccumulator1 < a)
      {
        motorMoveSteps1--;

        PIN_ON(MOTOR1_STEP_PORT, MOTOR1_STEP_PIN);
      }
    }

    // MOTOR 3
    if (motorMoveSteps2)
    {
      uint16_t a = motorAccumulator2;
      motorAccumulator2 += motorMoveSpeed2;
      if (motorAccumulator2 < a)
      {
        motorMoveSteps2--;

        PIN_ON(MOTOR2_STEP_PORT, MOTOR2_STEP_PIN);
      }
    }

    // MOTOR 4
    if (motorMoveSteps3)
    {
      uint16_t a = motorAccumulator3;
      motorAccumulator3 += motorMoveSpeed3;
      if (motorAccumulator3 < a)
      {
        motorMoveSteps3--;

        PIN_ON(MOTOR3_STEP_PORT, MOTOR3_STEP_PIN);
      }
    }
  }
  else
  {
    velocityUpdateCounter++;
    if (velocityUpdateCounter == VELOCITY_UPDATE_RATE)
    {
      velocityUpdateCounter = 0;

      if (sendPositionCounter)
      {
        sendPositionCounter--;
      }

      for (int i = 0; i < MOTOR_COUNT; i++)
      {
        if (*motorMoveSpeed[i] && !motors[i].nextMotorMoveSpeed)
        {
          bitSet(sendPosition, i);
        }

        *motorMoveSteps[i] = motors[i].nextMotorMoveSteps;
        *motorMoveSpeed[i] = motors[i].nextMotorMoveSpeed;
        digitalWrite(motors[i].dirPin, motors[i].dir);

        *motorAccumulator[i] = 65535;
      }
      nextMoveLoaded = false; // ready for new move
    }

    PIN_OFF(MOTOR0_STEP_PORT, MOTOR0_STEP_PIN);
    PIN_OFF(MOTOR1_STEP_PORT, MOTOR1_STEP_PIN);
    PIN_OFF(MOTOR2_STEP_PORT, MOTOR2_STEP_PIN);
    PIN_OFF(MOTOR3_STEP_PORT, MOTOR3_STEP_PIN);
  }
  portEXIT_CRITICAL_ISR(&timerMotionMux);
}

void setup()
{
  // setup serial connection
  SERIAL_DEVICE.begin(57600);

  messageQueue = xQueueCreate(200, sizeof(word));
  if (messageQueue == NULL)
  {
    Serial.println("Error creating the queue");
  }

  if (SERIAL_DEVICE_BT.begin("DFMoCo"))
  {
    SERIAL_DEVICE_BT.register_callback(bluetoothCallback);
  }

#if defined(FOCUS_PIN)
  pinMode(FOCUS_PIN, OUTPUT);
  PIN_OFF(0, FOCUS_PIN);
#endif

  pinMode(SHUTTER_PIN, OUTPUT);
  PIN_OFF(0, SHUTTER_PIN);

  pinMode(ENABLE_PIN, OUTPUT);
  PIN_OFF(0, ENABLE_PIN);

  pinMode(BLUETOOTH_LED_PIN, OUTPUT);
  PIN_ON(0, BLUETOOTH_LED_PIN);

  goMoReady = false;
  lastUserData = 0;
  msgState = MSG_STATE_START;
  velocityUpdateCounter = 0;
  sendPositionCounter = 10;
  nextMoveLoaded = false;

  for (int i = 0; i < 32; i++)
    txBuf[i] = 0;

  txBufPtr = txBuf;

  // initialize motor structures
  for (int i = 0; i < MOTOR_COUNT; i++)
  {
    // setup motor pins - you can customize/modify these after loop
    // default sets step/dir pairs together, with first four motors at 4/5, 6/7, 8/9, 10/11
    // then, for the Mega boards, it jumps to 28/29, 30/31, 32/33, 34/35
    switch (i)
    {
    case 0:
      motors[i].stepPin = MOTOR0_STEP_PIN;
      break;
    case 1:
      motors[i].stepPin = MOTOR1_STEP_PIN;
      break;
    case 2:
      motors[i].stepPin = MOTOR2_STEP_PIN;
      break;
    case 3:
      motors[i].stepPin = MOTOR3_STEP_PIN;
      break;
    }

    motors[i].dirPin = motors[i].stepPin + 1;
    motors[i].dir = true; // forward
    motors[i].positionReached = true;
    motors[i].position = 0L;
    motors[i].destination = 0L;

    motors[i].nextMotorMoveSteps = 0;
    motors[i].nextMotorMoveSpeed = 0;

    setPulsesPerSecond(i, DEFAUL_VELOCITY, true);

    for (int i = 0; i < MOTOR_COUNT; i++)
    {
      pinMode(motors[i].stepPin, OUTPUT);
      pinMode(motors[i].dirPin, OUTPUT);
    }
    // set initial direction
    for (int i = 0; i < MOTOR_COUNT; i++)
    {
      digitalWrite(motors[i].dirPin, motors[i].dir ? HIGH : LOW);
    }
  }

  sendMessage(MSG_HI, 0);

  timerMotion = timerBegin(0, 80, true);
  timerAttachInterrupt(timerMotion, &updateStepDirection, true);
  timerAlarmWrite(timerMotion, 25, true);
  timerAlarmEnable(timerMotion);
}

void loop()
{
  int32_t *ramValues = (int32_t *)malloc(sizeof(int32_t) * MOTOR_COUNT);
  int32_t *ramNotValues = (int32_t *)malloc(sizeof(int32_t) * MOTOR_COUNT);

  for (int i = 0; i < MOTOR_COUNT; i++)
  {
    if (ramValues[i] == ~ramNotValues[i])
    {
      motors[i].position = motors[i].destination = ramValues[i];
    }
  }

  while (true)
  {
    unsigned int element;
    messageCounter++;
    if (messageCounter % 3 == 0 && xQueueReceive(messageQueue, &element, 0) == pdTRUE)
    {
      sendMessageQueue(highByte(element), lowByte(element));
    }

    if (!serialBluetoothEnabled && ((millis() - lastBluetoothLedMillis) > 600))
    {
      if (lastBluetoothLedState)
      {
        PIN_OFF(0, BLUETOOTH_LED_PIN);
      }
      else
      {
        PIN_ON(0, BLUETOOTH_LED_PIN);
      }
      lastBluetoothLedState = !lastBluetoothLedState;
      lastBluetoothLedMillis = millis();
    }
    if (!nextMoveLoaded)
      updateMotorVelocities();

    processSerialCommand();
    if (cameraMode != CAM_MODE_NONE)
    {
      processCameraMode();
    }

    if (!sendPositionCounter)
    {
      sendPositionCounter = 20;

      byte i;
      for (i = 0; i < MOTOR_COUNT; i++)
      {
        if (bitRead(motorMoving, i) || bitRead(sendPosition, i))
        {
          if (cameraMode == CAM_MODE_NONE || bitRead(sendPosition, i))
          {
            sendMessage(MSG_MP, i);
          }
          ramValues[i] = motors[i].position;
          ramNotValues[i] = ~motors[i].position;
        }
        if (motors[i].position == motors[i].destination)
        {
          motors[i].positionReached = true;
        }
      }

      sendPosition = 0;
    }
  }
}

/**
 * Update velocities.
 */

void IRAM_ATTR updateMotorVelocities()
{
  for (int m = 0; m < MOTOR_COUNT; m++)
  {
    Motor *motor = &motors[m];
    motor->nextMotorMoveSteps = 0;
    motor->nextMotorMoveSpeed = 0;

    if (bitRead(motorMoving, m))
    {
      int seg = motor->currentMove;

      if (motor->moveTime[seg] == 0)
      {
        bitClear(motorMoving, m);
      }
      else
      {
        float originalMoveTime = motor->currentMoveTime;
        int originalMove = motor->currentMove;

        motor->currentMoveTime += 0.05f;

        if (motor->currentMoveTime >= motor->moveTime[seg])
        {
          motor->currentMoveTime -= motor->moveTime[seg];
          motor->currentMove++;
          seg++;
        }
        float t = motor->currentMoveTime;
        int32_t xn = (int32_t)(motor->movePosition[seg] + motor->moveVelocity[seg] * t + motor->moveAcceleration[seg] * t * t); // accel was already multiplied * 0.5

        int32_t dx = abs(xn - motor->position);

        if (!dx) // don't change direction flag unless we are actually stepping in new direction
          continue;

        boolean forward = xn > motor->position;

        if (forward != motor->dir) // direction setup time 1/20th second should be plenty
        {
          // revert everything except for dir flag
          motor->currentMoveTime = originalMoveTime;
          motor->currentMove = originalMove;
        }
        else
        {
          motor->nextMotorMoveSpeed = _max(1, _min(65535, dx * 65.6f));
          motor->nextMotorMoveSteps = dx;
          motor->position = xn;
        }

        motor->dir = forward;
      }
    }
  }
  nextMoveLoaded = true;
}

/*
 * Set up the axis for pulses per second (approximate)
 */
void setMaxAccelerationPerSecond(int motorIndex, uint16_t accelerationPerSecond)
{
  if (accelerationPerSecond > MAX_ACCELERATION)
    accelerationPerSecond = MAX_ACCELERATION;
  if (accelerationPerSecond < MIN_ACCELERATION)
    accelerationPerSecond = MIN_ACCELERATION;

  motors[motorIndex].maxAcceleration = accelerationPerSecond;
}

/*
 * Set up the axis for pulses per second (approximate)
 */
void setPulsesPerSecond(int motorIndex, uint16_t pulsesPerSecond, boolean setRamp)
{
  if (pulsesPerSecond > MAX_VELOCITY)
    pulsesPerSecond = MAX_VELOCITY;
  if (pulsesPerSecond < MIN_VELOCITY)
    pulsesPerSecond = MIN_VELOCITY;

  motors[motorIndex].maxVelocity = pulsesPerSecond;
  if (setRamp)
  {
    motors[motorIndex].maxAcceleration = pulsesPerSecond * 0.5f;
  }
}

void setupMotorMove(int motorIndex, int32_t destination)
{
  motors[motorIndex].destination = destination;

  if (destination != motors[motorIndex].position)
  {
    calculatePointToPoint(motorIndex, destination);
    bitSet(motorMoving, motorIndex);
  }
}

void hardStop()
{
  // set the destination to the current location, so they won't move any more
  for (int i = 0; i < MOTOR_COUNT; i++)
  {
    stopMotor(i, false, true);
  }
}

void normalStop()
{
  // set the destination to the current location, so they won't move any more
  for (int i = 0; i < MOTOR_COUNT; i++)
  {
    stopMotor(i, true, false);
  }
}

void stopMotor(int motorIndex, boolean fastStop, boolean hardStop)
{
  int32_t delta = (motors[motorIndex].destination - motors[motorIndex].position);
  if (!delta)
  {
    // motors[motorIndex].positionReached = true;
    // motors[motorIndex].nextMotorMoveSpeed = 0;
    // bitClear(motorMoving, motorIndex);
    return;
  }

  Motor *motor = &motors[motorIndex];
  int i;

  for (i = 0; i < P2P_MOVE_COUNT; i++)
  {
    motor->moveTime[i] = 0;
    motor->moveVelocity[i] = 0;
    motor->movePosition[i] = 0;
  }

  float v = VELOCITY_CONVERSION_FACTOR * motors[motorIndex].nextMotorMoveSpeed;
  float maxA = motor->maxAcceleration;
  if (hardStop)
  {
    maxA = MAX_ACCELERATION * 3;
  }
  else if (fastStop && maxA < motors[motorIndex].maxVelocity)
  {
    maxA = motors[motorIndex].maxVelocity;
  }

  float maxV = motor->maxVelocity;

  if (v > maxV)
    v = maxV;

  if (!motor->dir)
    v = -v;

  float t = fabs(v / maxA);

  motor->moveTime[0] = t;
  motor->movePosition[0] = motor->position;
  motor->moveVelocity[0] = v;
  motor->moveAcceleration[0] = (v > 0) ? -maxA : maxA;

  motor->moveTime[1] = 0;
  motor->movePosition[1] = (int32_t)(motor->movePosition[0] + motor->moveVelocity[0] * t + 0.5f * motor->moveAcceleration[0] * t * t);
  motor->moveVelocity[1] = 0;
  motor->moveAcceleration[1] = 0;

  motor->moveAcceleration[0] *= 0.5f;

  motor->destination = motor->movePosition[1];

  motor->currentMoveTime = 0;
  motor->currentMove = 0;
}
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

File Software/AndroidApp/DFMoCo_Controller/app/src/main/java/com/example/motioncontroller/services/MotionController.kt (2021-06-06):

package com.example.motioncontroller

import android.app.Notification
import android.app.NotificationChannel
import android.app.NotificationManager
import android.app.PendingIntent
import android.content.Context
import android.content.Intent
import android.os.Binder
import android.os.Build
import android.os.Handler
import android.os.IBinder
import android.util.Log
import androidx.appcompat.app.AppCompatActivity
import androidx.core.app.NotificationCompat
import androidx.core.content.ContextCompat
import androidx.localbroadcastmanager.content.LocalBroadcastManager
import com.example.motioncontroller.datasets.*
import kotlinx.android.synthetic.main.activity_main_page.*
import kotlin.time.ExperimentalTime

private const val CHANNEL_ID = "Motion_Controller_Service"
private const val NOTIFICATION_ID = 1

enum class MotionControllerCustomMode {
    NO_CUSTOM_MODE,
    TIMELAPSE,
    PANORAMA,
    FOCUS_STACKING,
    RESETTING,
}

val motorTypes = arrayListOf<MotorType>(
    object : MotorType {
        override val id: String = "nema_23_half_slider"
        override val name: String = "Nema 23 Slider"
        override val current: Double = 2.0
        override val microstepping: MotorTypeMicrostepping = MotorTypeMicrostepping.HALF
        override val operation: MotorTypeOperation = MotorTypeOperation.LINEAR
        override val operationSteps: Double = 100.0
        override val defaultSpeed: Int = 4500
    },
    object : MotorType {
        override val id: String = "nema_17_fourth_rotation"
        override val name: String = "Nema 17 Pan 27:1"
        override val current: Double = 0.8
        override val microstepping: MotorTypeMicrostepping = MotorTypeMicrostepping.QUARTER
        override val operation: MotorTypeOperation = MotorTypeOperation.ROTATION
        override val operationSteps: Double = 59.4
        override val defaultSpeed: Int = 1500
    }
)

@ExperimentalTime
@Suppress("UNCHECKED_CAST")
class MotionControllerService : BluetoothService() {
    private val binder = MotionControllerBinder()
    private val motors : List<MotorChannel> = List(4) { MotorChannel() }

    private var mHandler: Handler? = null
    private var jogModeState = 0
    private var jogModeMotor = 0
    private var jogModePower = 0
    private var jogModeStartSpeed = 0
    private var jogModeSpeed = 0

    private var notificationText = App.getContext().resources.getString(R.string.connecting)
    private var notificationActivity : Class<AppCompatActivity> = MainPage::class.java as Class<AppCompatActivity>
    private val notificationService = NotificationCompat.Builder(this, CHANNEL_ID)
        .setContentTitle(App.getContext().resources.getString(R.string.app_name))
        .setSmallIcon(R.drawable.ic_bluetooth_on)

    var init = false
    var motorCount = 0
    var version = ""
    var customMode = MotionControllerCustomMode.NO_CUSTOM_MODE
    var timelapseStatusData: TimelapseStatusData = TimelapseStatusData()

    companion object {
        const val EXTRA_MOTION_CONTROLLER_UPDATE = "motion-controller-update"
        const val EXTRA_MOTION_CONTROLLER_CUSTOM_MODE_UPDATE = "motion-controller-custom-mode-update"
        const val EXTRA_MOTION_CONTROLLER_SPEED_UPDATE: String = "motion-controller-speed-update"

        const val MOTION_CONTROLLER_POSITION_UPDATE_ACTION: String = "motion-controller-position-update-action"
        const val MOTION_CONTROLLER_POSITION_UPDATE_EXTRA: String = "motion-controller-position-update-extra"
        const val MOTION_CONTROLLER_DISCONNECT_ACTION: String = "motion-controller-disconnect-action"

        fun startService(context: Context) {
            val startIntent = Intent(context, MotionControllerService::class.java)
            ContextCompat.startForegroundService(context, startIntent)
        }

        fun stopService(context: Context) {
            val stopIntent = Intent(context, MotionControllerService::class.java)
            context.stopService(stopIntent)
        }
    }

    inner class MotionControllerBinder : Binder() {
        fun getService(): MotionControllerService = this@MotionControllerService
    }

    override fun onBind(intent: Intent?): IBinder {
        return binder
    }

    override fun onStartCommand(intent: Intent?, flags: Int, startId: Int): Int {
        Log.d("MotionControllerService", "Start")

        startForegroundService()

        return START_NOT_STICKY
    }

    private fun startForegroundService() {
        createNotificationChannel()
        val notification = createNotification(null)
        startForeground(NOTIFICATION_ID, notification)
    }

    private fun stopForegroundService() {
        Log.d("MotionControllerService", "Stop foreground service.")

        // Stop foreground service and remove the notification.
        stopForeground(true)

        // Stop the foreground service.
        stopSelf()
    }

    private fun createNotificationChannel() {
        if (Build.VERSION.SDK_INT >= Build.VERSION_CODES.O) {
            val serviceChannel = NotificationChannel(CHANNEL_ID, "Motion_Controller_Service_Channel",
                NotificationManager.IMPORTANCE_DEFAULT)
            serviceChannel.setSound(null, null)
            val manager = getSystemService(NotificationManager::class.java)
            manager!!.createNotificationChannel(serviceChannel)
        }
    }

    private fun createNotification(extraCustomMode: CustomModeType?): Notification {
        val notificationIntent = Intent(this, notificationActivity)
        if (extraCustomMode != null) {
            notificationIntent.putExtra(CUSTOM_MODE_EXTRA, extraCustomMode)
        }
        val pendingIntent = PendingIntent.getActivity(
            this,
            0, notificationIntent, PendingIntent.FLAG_CANCEL_CURRENT
        )

        return notificationService
            .setContentText(notificationText)
            .setContentIntent(pendingIntent)
            .build()
    }

    fun updateNotification(updateNotificationText: String?, updateNotificationActivity : Class<AppCompatActivity>?, extraCustomMode: CustomModeType?) {
        if (updateNotificationText != null) {
            notificationText = updateNotificationText
        }
        if (updateNotificationActivity != null) {
            notificationActivity = updateNotificationActivity
        }

        val notification = createNotification(extraCustomMode)
        val mNotificationManager = getSystemService(NOTIFICATION_SERVICE) as NotificationManager
        mNotificationManager.notify(NOTIFICATION_ID, notification)
    }

    fun connectAndInit(address: String) {
        connect(address)
        if (isConnected) {
            updateNotification(App.getContext().resources.getString(R.string.connected), null, null)
            requestInitData()
            listen()
        }
    }

    fun getMotorPosition(motorNumber: Int): Int {
        return motors[motorNumber - 1].position
    }
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

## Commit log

2021-03-11 add android application
    [ic_motor_active.xml, ic_motor_inactive.xml, ic_motor_reset.xml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]
2021-05-04 add documents
    [MotorAdapterPlate.step]
2021-05-29 update jog and timelapse
    [ic_zero_motor.xml, ic_zero_motor_background.xml, ic_zero_motor_foreground.xml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]
2021-06-01 fix motor name
